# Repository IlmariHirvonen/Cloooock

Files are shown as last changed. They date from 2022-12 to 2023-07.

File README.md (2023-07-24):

# Cloooock
A simple Arduino based eurorack clock module. I may add some stuff in the future like encoder acceleration.

Current functionality:
* BPM adjustment 30-9999 bpm
* Pause and play
* Time division adjustment
  * Press encoder to enter channel selection
  * Press encoder to select channel
  * Select with encoder between 1/1 to 1/128
  * Press encoder to go back to channel selection or play/pause button to restart clock

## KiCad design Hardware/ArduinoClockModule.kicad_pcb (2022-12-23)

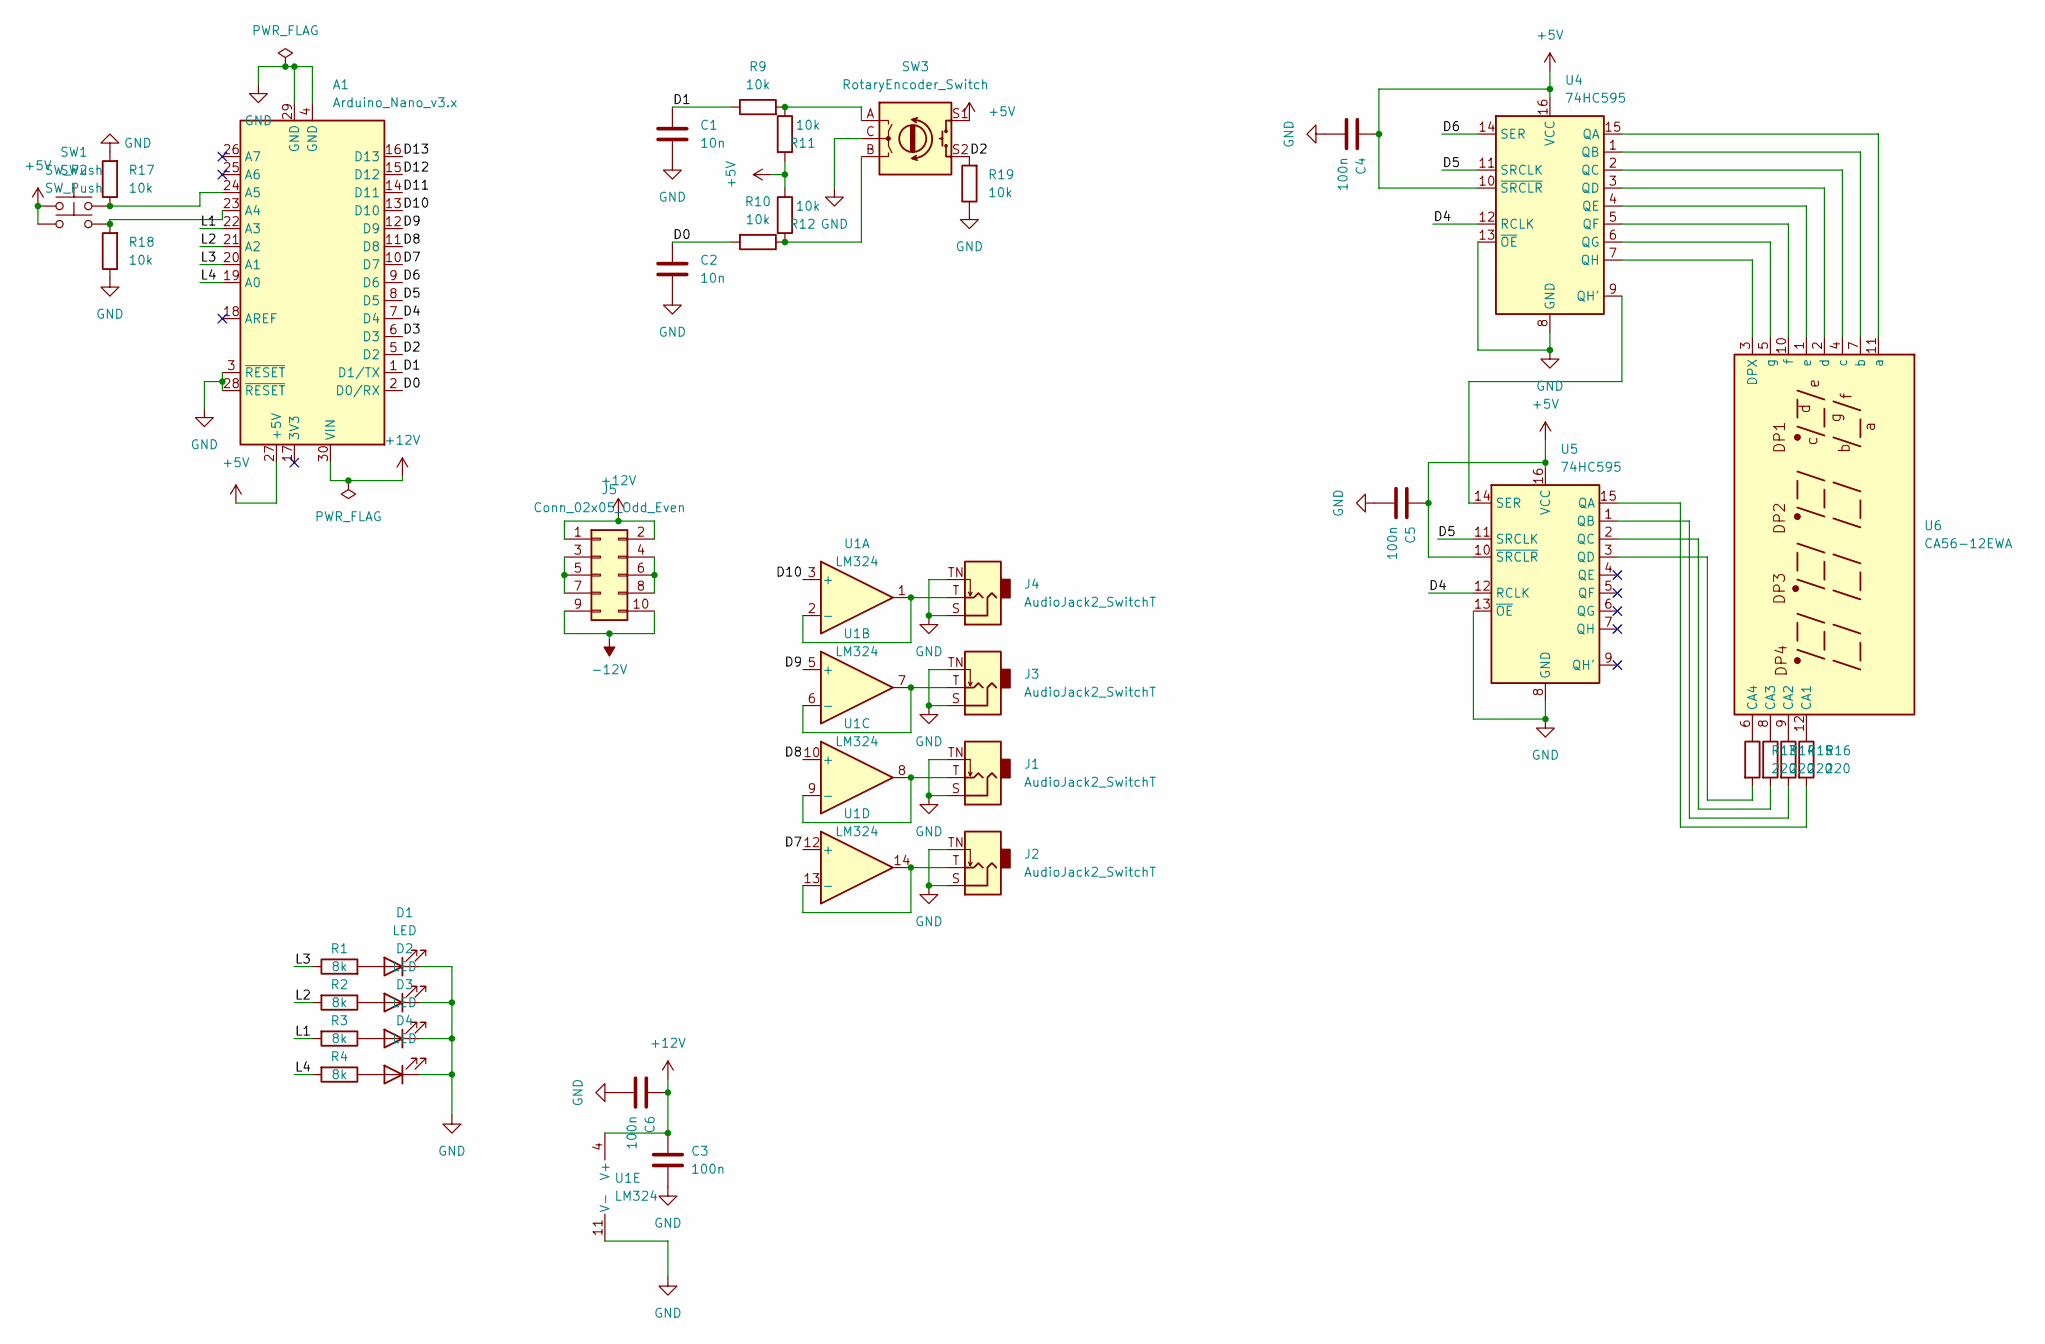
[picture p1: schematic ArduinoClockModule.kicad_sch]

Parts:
A1: Arduino_Nano_v3.x; Arduino_Nano
C1, C2: 10n; C_Disc_D3.0mm_W2.0mm_P2.50mm
C3, C4, C5, C6: 100n; C_Disc_D3.8mm_W2.6mm_P2.50mm
D1, D2, D3, D4: LED; LED_D3.0mm
J1, J2, J3, J4: AudioJack2_SwitchT; Thonkiconn
J5: Conn_02x05_Odd_Even; PinHeader_2x05_P2.54mm_Vertical
R1, R2, R3, R4: 8k; R_Axial_DIN0207_L6.3mm_D2.5mm_P7.62mm_Horizontal
R9, R10, R11, R12, R17, R18, R19: 10k; R_Axial_DIN0207_L6.3mm_D2.5mm_P7.62mm_Horizontal
R13, R14, R15, R16: 220; R_Axial_DIN0207_L6.3mm_D2.5mm_P7.62mm_Horizontal
SW1, SW2: SW_Push; SW_PUSH_6mm
SW3: RotaryEncoder_Switch; RotaryEncoder_Alps_EC11E-Switch_Vertical_H20mm
U1: LM324; DIP-14_W7.62mm
U4, U5: 74HC595; DIP-16_W7.62mm
U6: CA56-12EWA

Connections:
+5V: A1.27 (+5V), C4.1, C5.1, R11.2, R12.1, SW1.1, SW2.1, SW3.S1, U4.10 (~SRCLR), U4.16 (VCC), U5.10 (~SRCLR), U5.16 (VCC)
+12V: A1.30 (VIN), C3.1, C6.1, J5.1, J5.2, U1.4 (V+)
-12V: J5.9, J5.10
/D0: A1.2 (D0/RX), C2.1, R10.2
/D1: A1.1 (D1/TX), C1.1, R9.1
/D2: A1.5 (D2), R19.2, SW3.S2
/D3: A1.6 (D3)
/D4: A1.7 (D4), U4.12 (RCLK), U5.12 (RCLK)
/D5: A1.8 (D5), U4.11 (SRCLK), U5.11 (SRCLK)
/D6: A1.9 (D6), U4.14 (SER)
/D7: A1.10 (D7), U1.12 (+)
/D8: A1.11 (D8), U1.10 (+)
/D9: A1.12 (D9), U1.5 (+)
/D10: A1.13 (D10), U1.3 (+)
/D11: A1.14 (D11)
/D12: A1.15 (D12)
/D13: A1.16 (D13)
/L1: A1.22 (A3), R3.2
/L2: A1.21 (A2), R2.2
/L3: A1.20 (A1), R1.1
/L4: A1.19 (A0), R4.2
GND: A1.3 (~RESET), A1.4 (GND), A1.28 (~RESET), A1.29 (GND), C1.2, C2.2, C3.2, C4.2, C5.2, C6.2, D1.1 (K), D2.1 (K), D3.1 (K), D4.1 (K), J1.S, J1.TN, J2.S, J2.TN, J3.S, J3.TN, J4.S, J4.TN, R17.2, R18.1, R19.1, SW3.C, U1.11 (V-), U4.8 (GND), U4.13 (~OE), U5.8 (GND), U5.13 (~OE)
unnamed: A1.23 (A4), R18.2, SW2.2
unnamed: A1.24 (A5), R17.1, SW1.2
unnamed: D1.2 (A), R1.2
unnamed: D2.2 (A), R2.1
unnamed: D3.2 (A), R3.1
unnamed: D4.2 (A), R4.1
unnamed: J1.T, U1.8, U1.9 (-)
unnamed: J2.T, U1.13 (-), U1.14
unnamed: J3.T, U1.6 (-), U1.7
unnamed: J4.T, U1.1, U1.2 (-)
unnamed: J5.3, J5.5, J5.7
unnamed: J5.4, J5.6, J5.8
unnamed: R10.1, R12.2, SW3.B
unnamed: R9.2, R11.1, SW3.A
unnamed: R13.1, U6.6 (CA4)
unnamed: R13.2, U5.3 (QD)
unnamed: R14.1, U6.8 (CA3)
unnamed: R14.2, U5.2 (QC)
unnamed: R15.1, U6.9 (CA2)
unnamed: R15.2, U5.1 (QB)
unnamed: R16.1, U6.12 (CA1)
unnamed: R16.2, U5.15 (QA)
unnamed: U4.1 (QB), U6.7 (b)
unnamed: U4.2 (QC), U6.4 (c)
unnamed: U4.3 (QD), U6.2 (d)
unnamed: U4.4 (QE), U6.1 (e)
unnamed: U4.5 (QF), U6.10 (f)
unnamed: U4.6 (QG), U6.5 (g)
unnamed: U4.7 (QH), U6.3 (DPX)
unnamed: U4.15 (QA), U6.11 (a)
unnamed: U4.9 (QH'), U5.14 (SER)

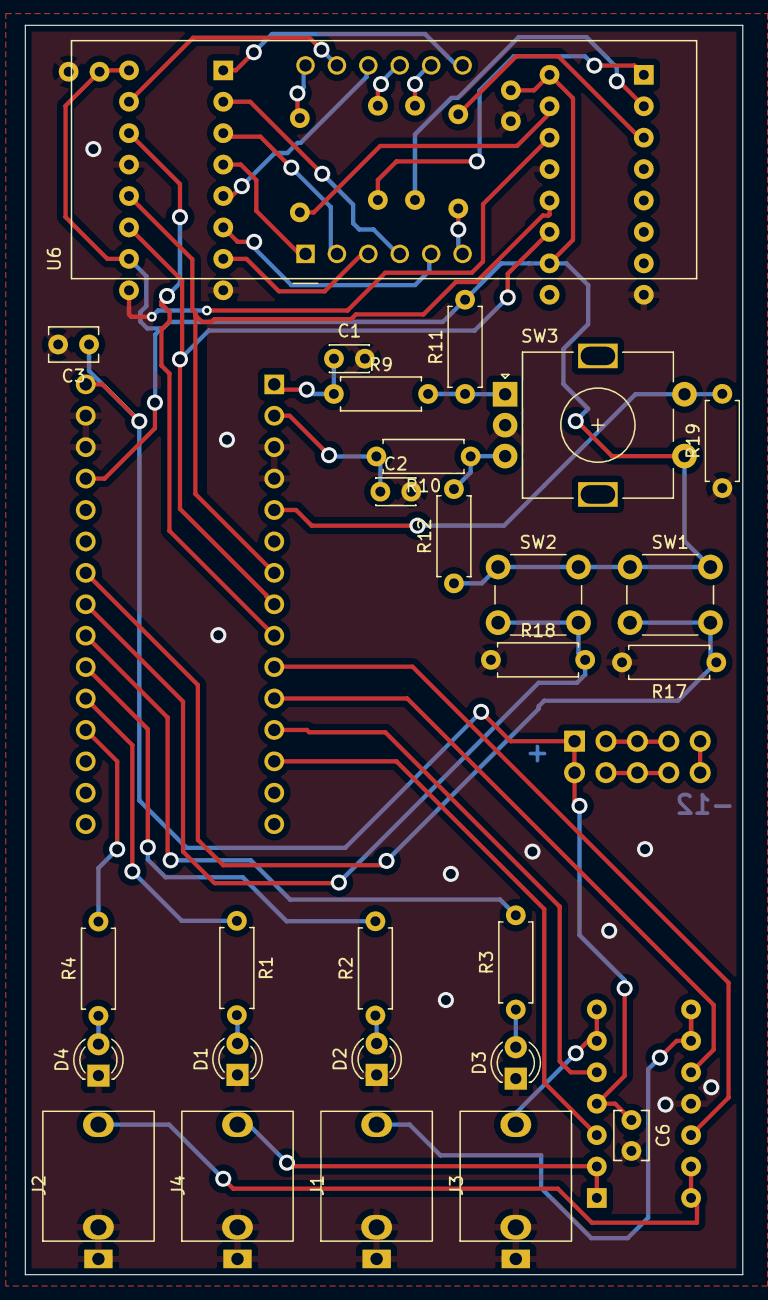
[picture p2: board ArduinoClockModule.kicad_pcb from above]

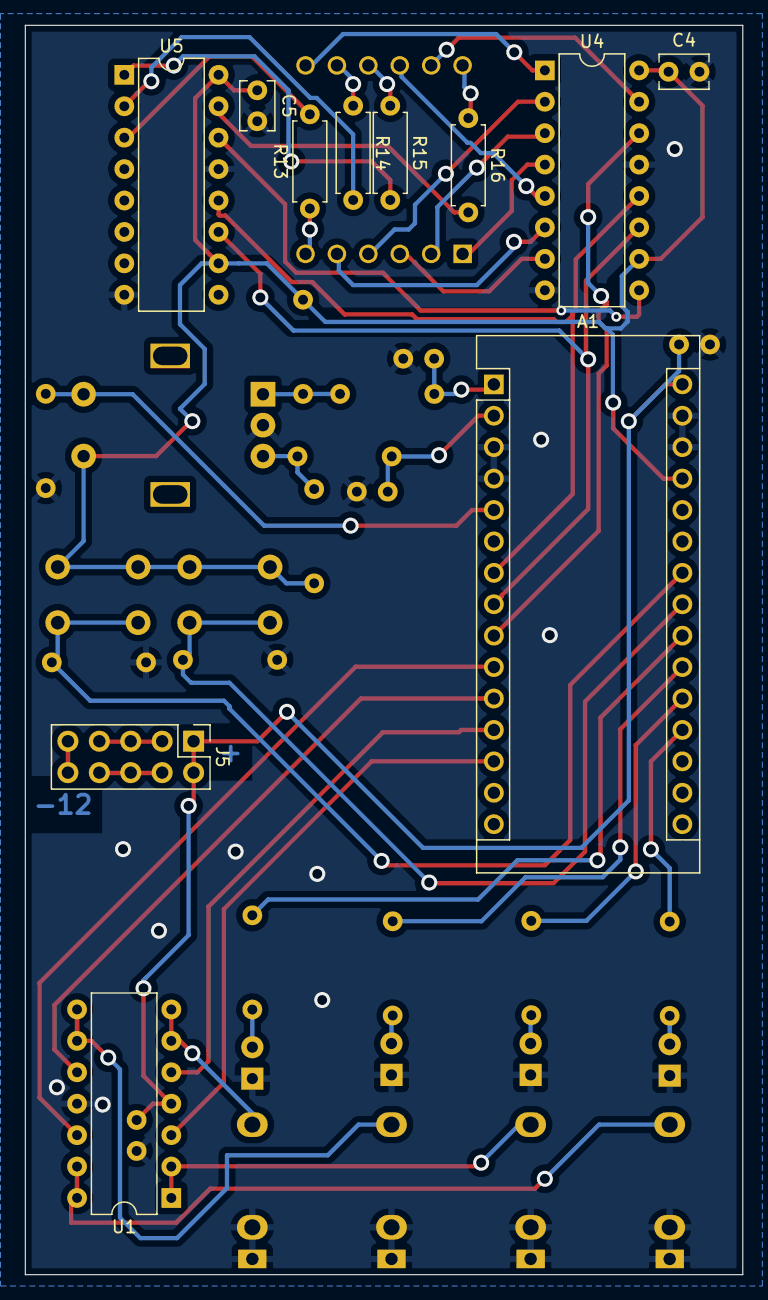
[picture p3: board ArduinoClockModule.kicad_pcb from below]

Board: 2 copper layers, 58.0 x 101.0 mm, 38 parts (11 on the bottom side), 49 nets.

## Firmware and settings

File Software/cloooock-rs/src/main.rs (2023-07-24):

#![no_std]
#![no_main]
#![feature(abi_avr_interrupt)]

use avr_device::atmega328p::TC1;
use avr_device::{atmega328p::tc1::tccr1b::CS1_A, interrupt::Mutex};

use arduino_hal::{
    adc::{self},
    prelude::*,
};
use cloooock_rs::cv_output::ClockChannel;
use cloooock_rs::state_machine::{ButtonPressed, DeviceState};
use cloooock_rs::time::TicksPerBar;
use cloooock_rs::time::TICK_RATE;
use core::cell::RefCell;
use core::mem;
use ufmt::{uWrite, uwriteln};

use cloooock_rs::cv_output::Prescaler;
use cloooock_rs::display::Display;
use cloooock_rs::time::BPM;
use cloooock_rs::encoder::Encoder;
use panic_halt as _;

//const NUM_CHANNELS: u8 = 4;
const MIN_BPM: u16 = 30;
const MAX_BPM: u16 = 9999;

struct ClockChannels {
    bar_ticks: TicksPerBar,
    channels: [ClockChannel; 4],
}

// global mutable state
static TICKS: Mutex<RefCell<u32>> = Mutex::new(RefCell::new(0));
static MASTER_BPM: Mutex<RefCell<BPM>> = Mutex::new(RefCell::new(BPM::new(120)));
// output devices
static mut CLOCK_CHANNELS: mem::MaybeUninit<ClockChannels> = mem::MaybeUninit::uninit();

#[arduino_hal::entry]
fn main() -> ! {
    let mut state = DeviceState::Running;
    let mut selected_channel: i8 = 0;
    let dp = arduino_hal::Peripherals::take().unwrap();
    let pins = arduino_hal::pins!(dp);
    let adc = arduino_hal::Adc::new(dp.ADC, Default::default());

    let mut serial = arduino_hal::default_serial!(dp, pins, 57600);

    // Pinout
    // Purpose  Arduino Pin     AVR Pin
    // Led 1    A3              PC3
    // Led 2    A2              PC2
    // Led 3    A1              PC1
    // Led 4    A0              PC0
    let led_0 = pins.a0.into_output().downgrade();
    let led_1 = pins.a1.into_output().downgrade();
    let led_2 = pins.a2.into_output().downgrade();
    let led_3 = pins.a3.into_output().downgrade();

    let pause_button = pins.a4.into_floating_input().downgrade();
    let mut pause_button_was_pressed: bool;
    let mut pause_button_previous_state = false;

    let output_0 = pins.d7.into_output().downgrade();
    let output_1 = pins.d10.into_output().downgrade();
    let output_2 = pins.d8.into_output().downgrade();
    let output_3 = pins.d9.into_output().downgrade();
    // pinout
    // let encoder_button = pins.d2.into_input().downgrade();
    let encoder_dt_channel = &adc::channel::ADC6.into_channel();
    let encoder_clk_channel = &adc::channel::ADC7.into_channel();
    let encoder_button = pins.d2.into_floating_input().downgrade();
    let mut encoder_button_was_pressed: bool;
    let mut encoder_button_previous_state = false;

    let display_latch_pin = pins.d4.into_output().downgrade();
    let display_clk_pin = pins.d5.into_output().downgrade();
    let display_data_pin = pins.d6.into_output().downgrade();
    let mut display = Display::new(display_clk_pin, display_data_pin, display_latch_pin);

    let mut encoder = Encoder::new(
        adc,
        encoder_clk_channel,
        encoder_dt_channel,
    );

    unsafe {
        // SAFETY: Interrupts are not enabled at this point so we can safely write the global
        // variable here.  A memory barrier afterwards ensures the compiler won't reorder this
        // after any operation that enables interrupts.
        avr_device::interrupt::free(|cs| {
            let bpm_ref = MASTER_BPM.borrow(cs).borrow();
            let ticks_per_bar = TicksPerBar::from(*bpm_ref).ticks;
            CLOCK_CHANNELS = mem::MaybeUninit::new(ClockChannels {
                bar_ticks: TicksPerBar::from(*bpm_ref),
                channels: [
                    ClockChannel::new(led_0, output_0, Prescaler::new(1, 2), ticks_per_bar),
                    ClockChannel::new(led_1, output_1, Prescaler::new(1, 4), ticks_per_bar),
                    ClockChannel::new(led_2, output_2, Prescaler::new(1, 6), ticks_per_bar),
                    ClockChannel::new(led_3, output_3, Prescaler::new(1, 8), ticks_per_bar),
                ],
            });
            core::sync::atomic::compiler_fence(core::sync::atomic::Ordering::SeqCst);
        });
    }

    // timers
    let tmr1: TC1 = dp.TC1;
    rig_timer1(&tmr1, &mut serial);

    ufmt::uwriteln!(&mut serial, "Start enable interrupts").void_unwrap();
    // Enable interrupts globally, not a replacement for the specific interrupt enable
    unsafe {
        // SAFETY: Not inside a critical section and any non-atomic operations have been completed
        // at this point.
        avr_device::interrupt::enable();
    }
    ufmt::uwriteln!(&mut serial, "Done enable interrupts").void_unwrap();

    loop {
        if pause_button_previous_state && pause_button.is_high() {
            pause_button_was_pressed = true;
        } else {
            pause_button_was_pressed = false;
        }
        pause_button_previous_state = pause_button.is_low();

        if encoder_button_previous_state && encoder_button.is_high() {
            encoder_button_was_pressed = true;
        } else {
            encoder_button_was_pressed = false;
        }
        encoder_button_previous_state = encoder_button.is_low();

        match state {
            DeviceState::Running => {
                if let Some(change) = encoder.poll() {
                    avr_device::interrupt::free(|cs| {
                        let mut bpm_ref = MASTER_BPM.borrow(cs).borrow_mut();
                        if !((bpm_ref.bpm <= MIN_BPM && change < 0)
                            || (bpm_ref.bpm >= MAX_BPM && change > 0))
                        {
                            *bpm_ref = *bpm_ref + change;
                        }

                        unsafe {
                            (&mut *CLOCK_CHANNELS.as_mut_ptr()).bar_ticks =
                                TicksPerBar::from(*bpm_ref);
                        }
                        let state = unsafe { &mut *CLOCK_CHANNELS.as_mut_ptr() };
                        let ticks_per_bar = TicksPerBar::from(*bpm_ref).ticks;
                        for channel in state.channels.iter_mut() {
                            channel.calculate_threshold(ticks_per_bar);
                        }
                    });
                }
                avr_device::interrupt::free(|cs| {
                    //let bpm_ref = MASTER_BPM.borrow(cs).borrow();
                    let mut ticks_ref = TICKS.borrow(cs).borrow_mut();
                    let state = unsafe { &mut *CLOCK_CHANNELS.as_mut_ptr() };
                    if *ticks_ref >= state.bar_ticks.ticks {
                        *ticks_ref = 0;
                        for channel in state.channels.iter_mut() {
                            channel.reset_threshold();
                        }
                    }
                    for channel in state.channels.iter_mut() {
                        channel.update(*ticks_ref);
                    }
                });
                avr_device::interrupt::free(|cs| {
                    let bpm_ref = MASTER_BPM.borrow(cs).borrow();
                    display.update(*bpm_ref);
                });
                if pause_button_was_pressed {
                    //ufmt::uwriteln!(&mut serial, "Pausing").void_unwrap();
                    state = state.transition(ButtonPressed::PauseButton);
                }
                if encoder_button_was_pressed {
                    let clock_channels = unsafe { &mut *CLOCK_CHANNELS.as_mut_ptr() };
                    for channel in clock_channels.channels.iter_mut() {
                        channel.set_led(false);
                    }
                    clock_channels.channels[selected_channel as usize].set_led(true);
                    state = state.transition(ButtonPressed::EncoderButton);
                }
            }

            DeviceState::Paused => {
                if pause_button_was_pressed {
                    state = state.transition(ButtonPressed::PauseButton);
                }
                avr_device::interrupt::free(|cs| {
                    let bpm_ref = MASTER_BPM.borrow(cs).borrow();
                    display.update(*bpm_ref);
                });
            }

            DeviceState::SelectingChannel => {
                let clock_channels = unsafe { &mut *CLOCK_CHANNELS.as_mut_ptr() };
                if let Some(change) = encoder.poll() {
                    selected_channel += change;
                    if selected_channel > 3 {
                        selected_channel = 0;
                    } else if selected_channel < 0 {
                        selected_channel = 3;
                    }
                    for channel in clock_channels.channels.iter_mut() {
                        channel.set_led(false);
                    }
                    clock_channels.channels[selected_channel as usize].set_led(true);
                }
                if encoder_button_was_pressed {
                    for channel in clock_channels.channels.iter_mut() {
                        channel.set_led(false);
                    }
                    clock_channels.channels[selected_channel as usize].set_led(true);
                    state = state.transition(ButtonPressed::EncoderButton);
                }
                if pause_button_was_pressed {
                    for channel in clock_channels.channels.iter_mut() {
                        channel.reset_threshold();
                    }
                    state = state.transition(ButtonPressed::PauseButton);
                }
                avr_device::interrupt::free(|cs| {
                    let bpm_ref = MASTER_BPM.borrow(cs).borrow();
                    display.update(*bpm_ref);
                });
            }
            DeviceState::SettingDivisionState => {
                let clock_channels = unsafe { &mut *CLOCK_CHANNELS.as_mut_ptr() };
                if let Some(change) = encoder.poll() {
                    clock_channels.channels[selected_channel as usize].set_led(true);
                    clock_channels.channels[selected_channel as usize]
                        .update_denominator(change, clock_channels.bar_ticks.ticks);
                }
                display
                    .update(clock_channels.channels[selected_channel as usize].get_denominator());
                if encoder_button_was_pressed {
                    for channel in clock_channels.channels.iter_mut() {
                        channel.set_led(false);
                    }
                    clock_channels.channels[selected_channel as usize].set_led(true);
                    state = state.transition(ButtonPressed::EncoderButton);
                }
                if pause_button_was_pressed {
                    for channel in clock_channels.channels.iter_mut() {
                        channel.reset_threshold();
                    }
                    state = state.transition(ButtonPressed::PauseButton);
                }
            }
        }
    }
}

pub const fn calc_overflow(clock_hz: u32, target_hz: u32, prescale: u32) -> u32 {
    /*
    https://github.com/Rahix/avr-hal/issues/75
    reversing the formula F = 16 MHz / (256 * (1 + 15624)) = 4 Hz
     */
    clock_hz / target_hz / prescale - 1
}

fn rig_timer1<W: uWrite<Error = void::Void>>(tmr1: &TC1, serial: &mut W) {
    /*
     https://ww1.microchip.com/downloads/en/DeviceDoc/Atmel-7810-Automotive-Microcontrollers-ATmega328P_Datasheet.pdf
     section 15.11
    */
    use arduino_hal::clock::Clock;

    const ARDUINO_UNO_CLOCK_FREQUENCY_HZ: u32 = arduino_hal::DefaultClock::FREQ;
    const CLOCK_SOURCE: CS1_A = CS1_A::PRESCALE_8;
    let clock_divisor: u32 = match CLOCK_SOURCE {
        CS1_A::DIRECT => 1,
        CS1_A::PRESCALE_8 => 8,
        CS1_A::PRESCALE_64 => 64,
        CS1_A::PRESCALE_256 => 256,
        CS1_A::PRESCALE_1024 => 1024,
        CS1_A::NO_CLOCK | CS1_A::EXT_FALLING | CS1_A::EXT_RISING => {
            uwriteln!(serial, "uhoh, code tried to set the clock source to something other than a static prescaler {}", CLOCK_SOURCE as usize)
                .void_unwrap();
            1
        }
    };

    let ticks = calc_overflow(ARDUINO_UNO_CLOCK_FREQUENCY_HZ, TICK_RATE, clock_divisor) as u16;
    ufmt::uwriteln!(
        serial,
        "configuring timer output compare register = {}\r",
        ticks
    )
    .void_unwrap();

    tmr1.tccr1a.write(|w| w.wgm1().bits(0b00));
    tmr1.tccr1b.write(|w| {
        w.cs1()
            //.prescale_256()
            .variant(CLOCK_SOURCE)
            .wgm1()
            .bits(0b01)
    });
    tmr1.ocr1a.write(|w| unsafe { w.bits(ticks) });
    tmr1.timsk1.write(|w| w.ocie1a().set_bit()); //enable this specific interrupt
}

#[avr_device::interrupt(atmega328p)]
fn TIMER1_COMPA() {
    avr_device::interrupt::free(|cs| {
        // Interrupts are disabled here
        let mut ticks_ref = TICKS.borrow(cs).borrow_mut();
        *ticks_ref += 1;
    });
}

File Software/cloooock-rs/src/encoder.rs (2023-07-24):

use arduino_hal::{
    adc::{self, Channel},
    clock::MHz16,
    hal::usart::Usart0,
    prelude::*,
    Adc,
};

pub struct Encoder<'a> {
    adc: Adc,
    clk_channel: &'a Channel,
    dt_channel: &'a Channel,
    last_clk: bool,
}

impl<'a> Encoder<'a> {
    fn analog_read(adc: &mut Adc, channel: &adc::Channel) -> u16 {
        adc.read_blocking(channel)
    }

    pub fn new(adc: Adc, clk_channel: &'a Channel, dt_channel: &'a Channel) -> Self {
        Encoder {
            adc,
            clk_channel,
            dt_channel,
            last_clk: false,
        }
    }

    pub fn debug(&mut self, serial: &mut Usart0<MHz16>) {
        let clk = Self::analog_read(&mut self.adc, self.clk_channel);
        let dt = Self::analog_read(&mut self.adc, self.dt_channel);
        ufmt::uwriteln!(serial, "{} {}\r", clk, dt).void_unwrap();
    }

    pub fn poll(&mut self) -> Option<i8> {
        fn to_bool(x: u16) -> bool {
            x > (1024u16 / 2)
        }
        let current_clk = Self::analog_read(&mut self.adc, self.clk_channel);
        let current_dt = Self::analog_read(&mut self.adc, self.dt_channel);
        let current_clk = to_bool(current_clk);
        let current_dt = to_bool(current_dt);

        // on falling edge
        let ret_val = if !current_clk && self.last_clk {
            match current_dt {
                true => Some(-1),
                false => Some(1),
            }
        } else {
            None
        };
        self.last_clk = current_clk;
        ret_val
    }
}

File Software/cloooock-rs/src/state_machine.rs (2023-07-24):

pub enum ButtonPressed {
    PauseButton,
    EncoderButton,
}

pub enum DeviceState {
    Running,
    Paused,
    SelectingChannel,
    SettingDivisionState,
}

impl DeviceState {
    pub fn transition(self, button: ButtonPressed) -> DeviceState {
        match (self, button) {
            (DeviceState::Running, ButtonPressed::PauseButton) => DeviceState::Paused,
            (DeviceState::Running, ButtonPressed::EncoderButton) => DeviceState::SelectingChannel,

            (DeviceState::Paused, ButtonPressed::PauseButton) => DeviceState::Running,
            (DeviceState::Paused, ButtonPressed::EncoderButton) => DeviceState::SelectingChannel,

            (DeviceState::SelectingChannel, ButtonPressed::PauseButton) => DeviceState::Running,
            (DeviceState::SelectingChannel, ButtonPressed::EncoderButton) => {
                DeviceState::SettingDivisionState
            }

            (DeviceState::SettingDivisionState, ButtonPressed::PauseButton) => DeviceState::Running,
            (DeviceState::SettingDivisionState, ButtonPressed::EncoderButton) => {
                DeviceState::SelectingChannel
            }
        }
    }
}
